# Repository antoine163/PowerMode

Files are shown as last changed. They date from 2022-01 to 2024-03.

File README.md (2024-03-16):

# PowerMod
Module d’alimentation compatible avec les breadboard  
**Note**: Des valeurs de composants restent à finaliser...

## mod_boost_ap3012
Entrée (J1, J2): 5V  
Sortie boost (J3, J4): 24V

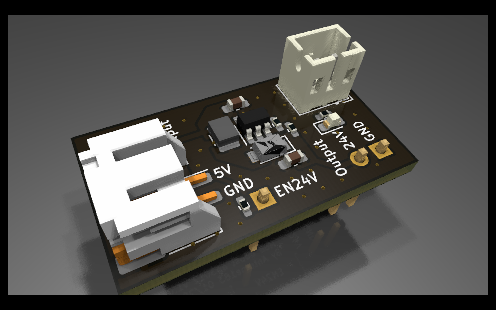
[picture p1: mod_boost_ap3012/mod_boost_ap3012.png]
mod_boost_ap3012


## mod_buck_bd95835efj
Entrée (J1, J2, J6): 12V / 1.5A  
Sortie buck (J4): 5.6V / 2A  
Sortie ldo (J7, J5): 5V / 1.2A  

**Attention:** Le courant max sur l'ensemble des sortie est de 3A.

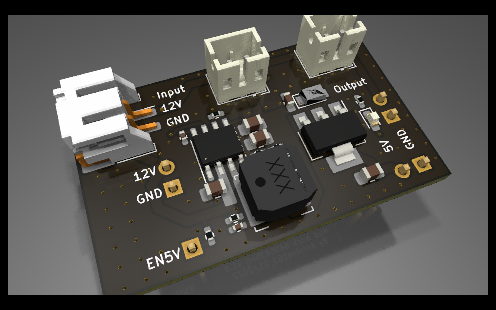
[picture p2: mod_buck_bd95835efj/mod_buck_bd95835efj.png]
mod_buck_bd95835efj


## mod_buck_xc9263
Entrée (J1, J2, J7): 12V  
Sortie 1 buck (J4): 5.35V  
Sortie 1 ldo (J5, J6): 5V / 200mA  
Sortie 2 buck (J8): 3.5V  
Sortie 2 ldo (J5, J6): 3.3V / 250mA  
Sortie 3 buck (J9): 2.1V  
Sortie 3 ldo (J5, J6): 1.8V / 200mA  

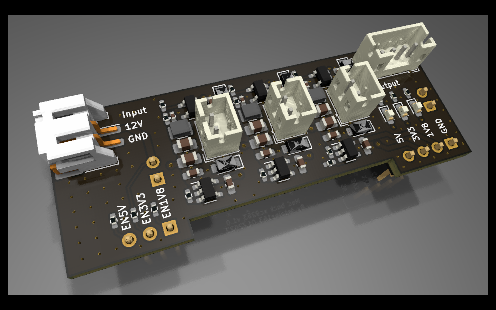
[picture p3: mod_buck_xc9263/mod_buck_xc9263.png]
mod_buck_xc9263
 
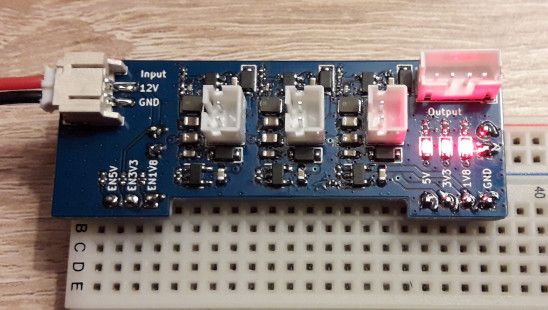
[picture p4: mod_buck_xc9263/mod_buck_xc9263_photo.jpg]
mod_buck_xc9263


# Models 3D
Certains modèles 3D ne sont pas inclus dans ce projet. Il vous faudra les télécharger sur le site des fabricants si vous en avez besoin.

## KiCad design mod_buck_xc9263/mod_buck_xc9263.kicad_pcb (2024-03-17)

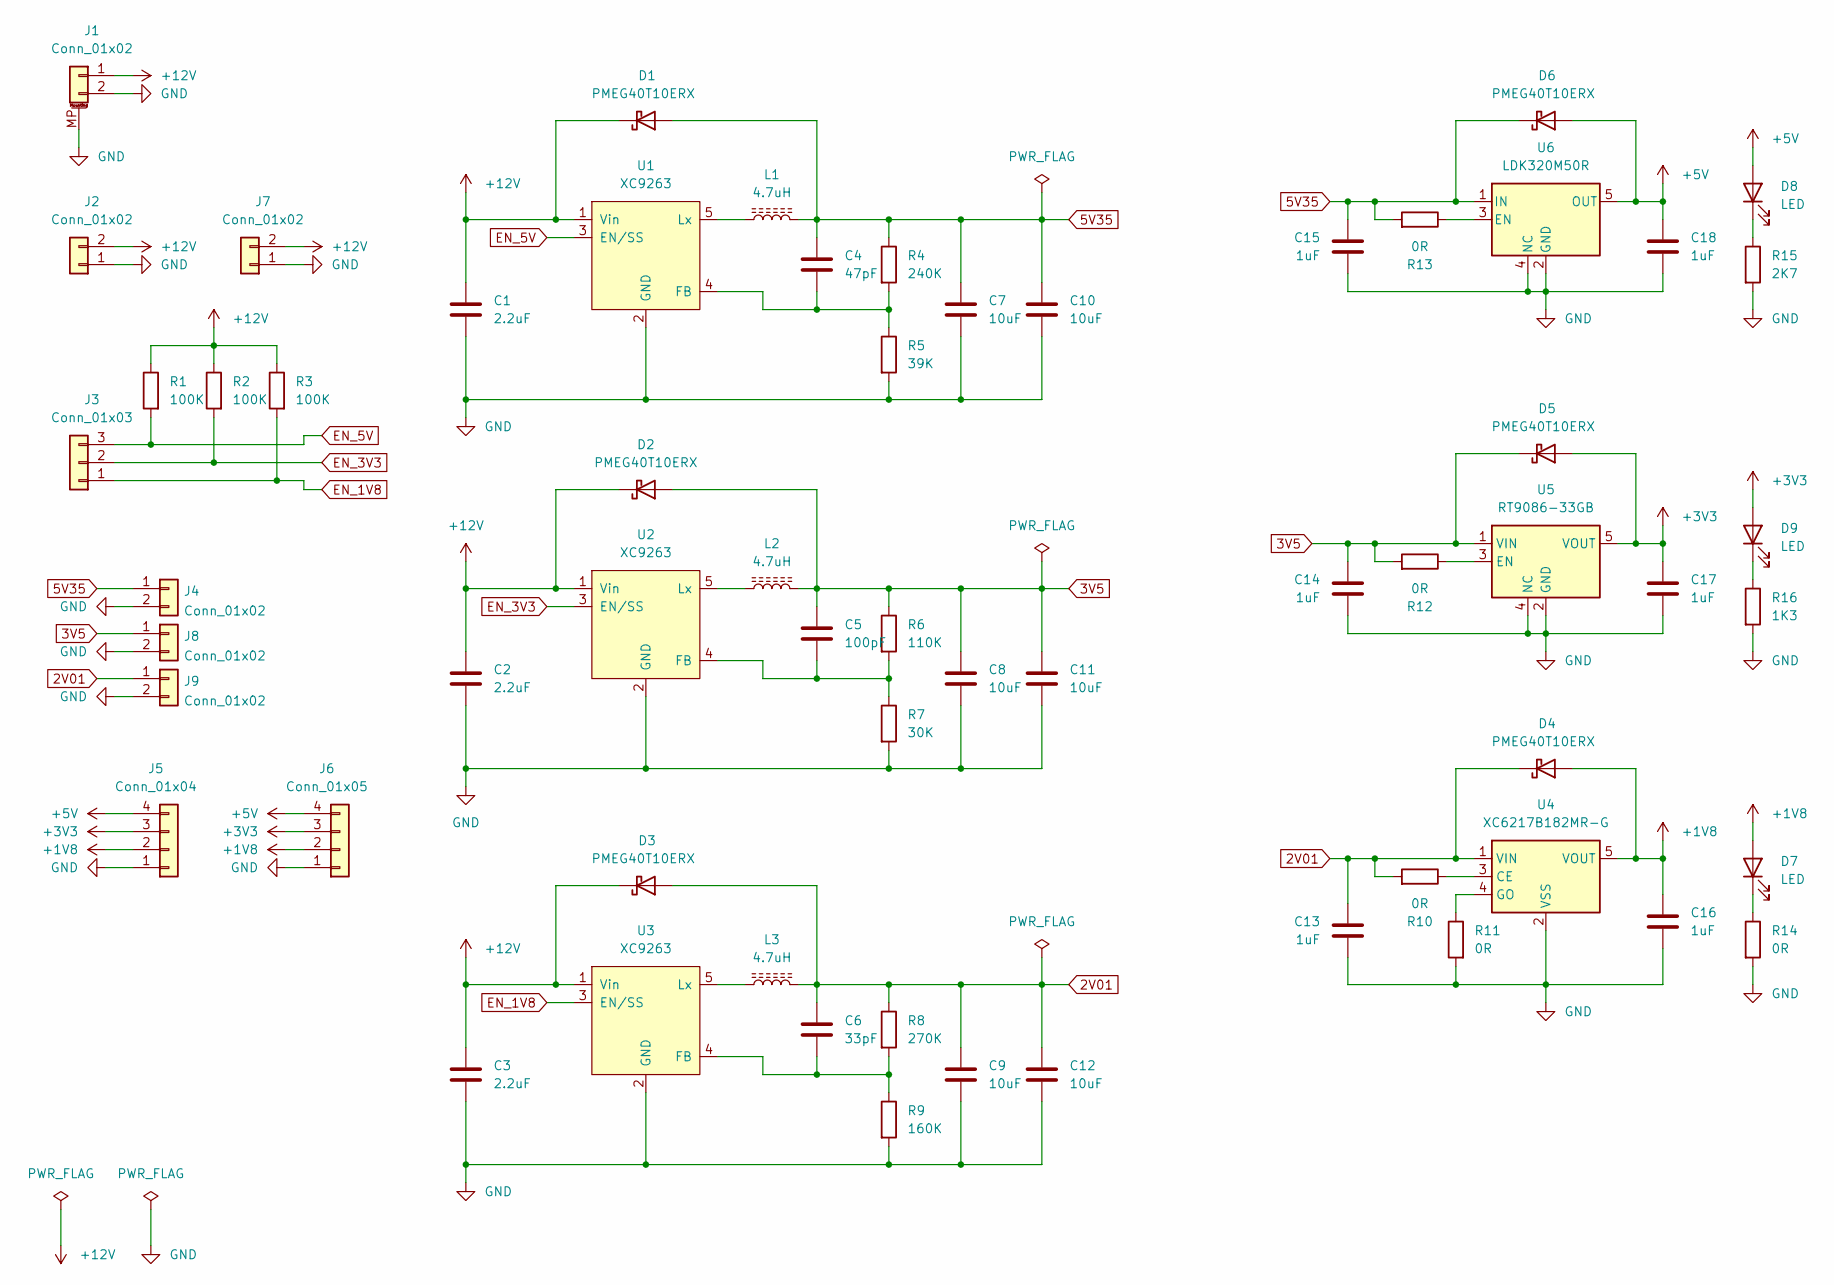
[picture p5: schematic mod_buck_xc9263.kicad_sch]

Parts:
C1, C2, C3: 2.2uF; C_0603_1608Metric_Pad1.08x0.95mm_HandSolder
C4: 47pF; C_0402_1005Metric_Pad0.74x0.62mm_HandSolder
C5: 100pF; C_0402_1005Metric_Pad0.74x0.62mm_HandSolder
C6: 33pF; C_0402_1005Metric_Pad0.74x0.62mm_HandSolder
C7, C8, C9, C10, C11, C12: 10uF; C_0805_2012Metric_Pad1.18x1.45mm_HandSolder
C13, C14, C15, C16, C17, C18: 1uF; C_0603_1608Metric_Pad1.08x0.95mm_HandSolder
D1, D2, D3, D4, D5, D6: PMEG40T10ERX; Nexperia_CFP3_SOD-123W
D7, D8, D9: LED; LED_0603_1608Metric_Pad1.05x0.95mm_HandSolder
J1: Conn_01x02; JST_PH_S2B-PH-SM4-TB_1x02-1MP_P2.00mm_Horizontal
J2, J7: Conn_01x02; PinHeader_1x02_P2.54mm_Vertical
J3: Conn_01x03; PinHeader_1x03_P2.54mm_Vertical
J4, J8, J9: Conn_01x02; JST_PH_B2B-PH-K_1x02_P2.00mm_Vertical
J5: Conn_01x04; JST_PH_B4B-PH-K_1x04_P2.00mm_Vertical
J6: Conn_01x05; PinHeader_1x04_P2.54mm_Vertical
L1, L2, L3: 4.7uH; L_TDK_VLS252012HBX_Handsoldering
R1, R2, R3: 100K; R_0402_1005Metric_Pad0.72x0.64mm_HandSolder
R4: 240K; R_0402_1005Metric_Pad0.72x0.64mm_HandSolder
R5: 39K; R_0402_1005Metric_Pad0.72x0.64mm_HandSolder
R6: 110K; R_0402_1005Metric_Pad0.72x0.64mm_HandSolder
R7: 30K; R_0402_1005Metric_Pad0.72x0.64mm_HandSolder
R8: 270K; R_0402_1005Metric_Pad0.72x0.64mm_HandSolder
R9: 160K; R_0402_1005Metric_Pad0.72x0.64mm_HandSolder
R10, R11, R12, R13, R14: 0R; R_0402_1005Metric_Pad0.72x0.64mm_HandSolder
R15: 2K7; R_0402_1005Metric_Pad0.72x0.64mm_HandSolder
R16: 1K3; R_0402_1005Metric_Pad0.72x0.64mm_HandSolder
U1, U2, U3: XC9263; SOT-23-5
U4: XC6217B182MR-G; SOT-23-5
U5: RT9086-33GB; SOT-23-5
U6: LDK320M50R; SOT-23-5

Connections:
2V01: C6.1, C9.1, C12.1, C13.2, D3.2 (A), D4.1 (K), J9.1, L3.2, R8.1, R10.2, U4.1 (VIN)
3V5: C5.1, C8.1, C11.1, C14.2, D2.2 (A), D5.1 (K), J8.1, L2.2, R6.1, R12.2, U5.1 (VIN)
5V35: C4.1, C7.1, C10.1, C15.2, D1.2 (A), D6.1 (K), J4.1, L1.2, R4.1, R13.2, U6.1 (IN)
+1V8: C16.1, D4.2 (A), D7.2 (A), J5.2, J6.2, U4.5 (VOUT)
+3V3: C17.1, D5.2 (A), D9.2 (A), J5.3, J6.3, U5.5 (VOUT)
+5V: C18.1, D6.2 (A), D8.2 (A), J5.4, J6.4, U6.5 (OUT)
+12V: C1.1, C2.1, C3.1, D1.1 (K), D2.1 (K), D3.1 (K), J1.1, J2.2, J7.2, R1.1, R2.1, R3.1, U1.1 (Vin), U2.1 (Vin), U3.1 (Vin)
EN_1V8: J3.1, R3.2, U3.3 (EN/SS)
EN_3V3: J3.2, R2.2, U2.3 (EN/SS)
EN_5V: J3.3, R1.2, U1.3 (EN/SS)
GND: C1.2, C2.2, C3.2, C7.2, C8.2, C9.2, C10.2, C11.2, C12.2, C13.1, C14.1, C15.1, C16.2, C17.2, C18.2, J1.2, J1.MP (MountPin), J2.1, J4.2, J5.1, J6.1, J7.1, J8.2, J9.2, R5.2, R7.2, R9.2, R11.2, R14.2, R15.2, R16.2, U1.2 (GND), U2.2 (GND), U3.2 (GND), U4.2 (VSS), U5.2 (GND), U5.4 (NC), U6.2 (GND), U6.4 (NC)
unnamed: C4.2, R4.2, R5.1, U1.4 (FB)
unnamed: C5.2, R6.2, R7.1, U2.4 (FB)
unnamed: C6.2, R8.2, R9.1, U3.4 (FB)
unnamed: D7.1 (K), R14.1
unnamed: D8.1 (K), R15.1
unnamed: D9.1 (K), R16.1
unnamed: L1.1, U1.5 (Lx)
unnamed: L2.1, U2.5 (Lx)
unnamed: L3.1, U3.5 (Lx)
unnamed: R10.1, U4.3 (CE)
unnamed: R11.1, U4.4 (GO)
unnamed: R12.1, U5.3 (EN)
unnamed: R13.1, U6.3 (EN)

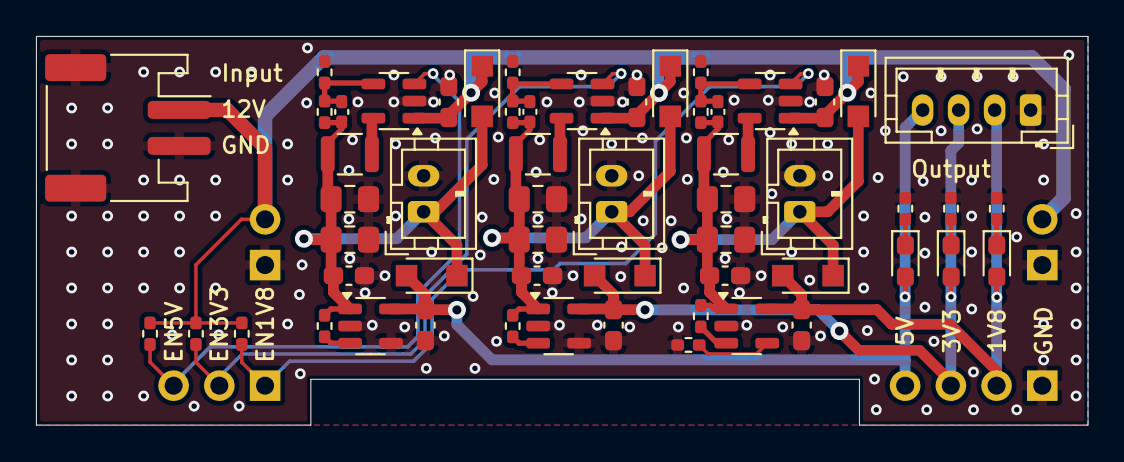
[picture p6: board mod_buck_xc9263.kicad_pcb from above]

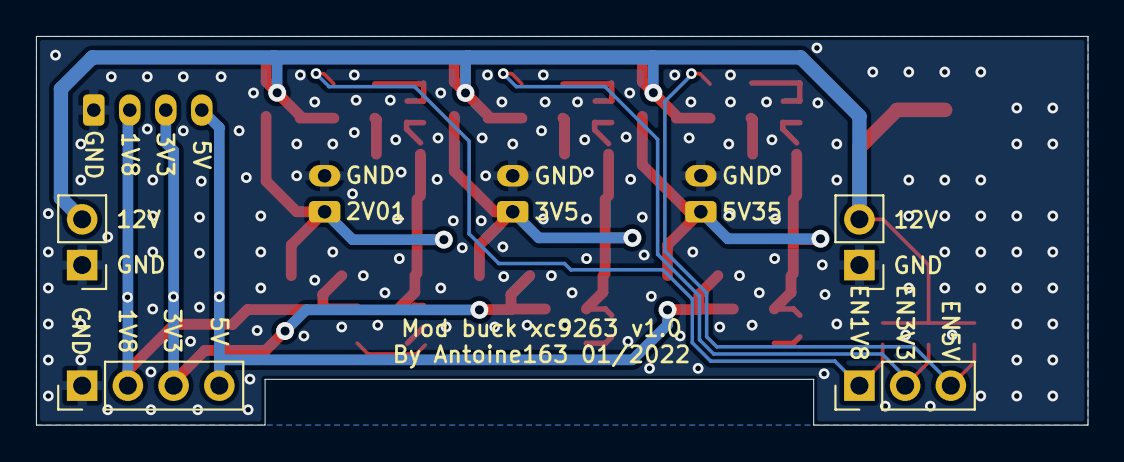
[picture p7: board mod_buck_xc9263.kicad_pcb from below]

Board: 2 copper layers, 58.4 x 21.6 mm, 61 parts (4 on the bottom side), 24 nets.

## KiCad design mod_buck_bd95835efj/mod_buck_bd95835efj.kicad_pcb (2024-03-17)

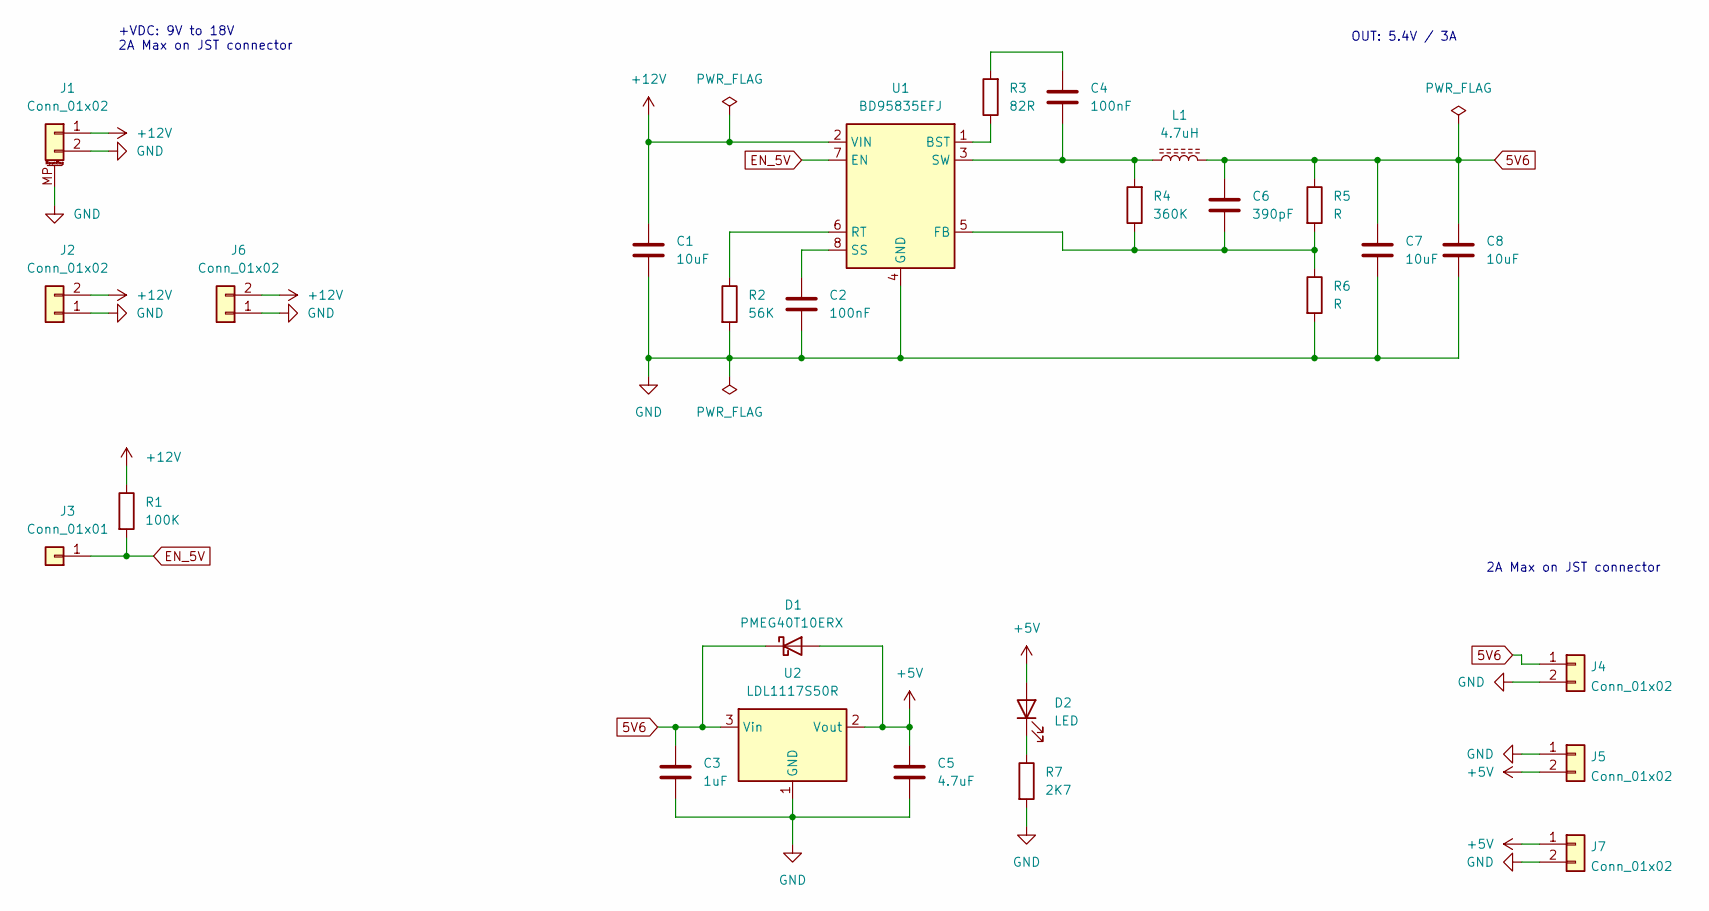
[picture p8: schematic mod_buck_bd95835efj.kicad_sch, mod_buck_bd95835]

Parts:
C1, C7, C8: 10uF; C_0805_2012Metric_Pad1.18x1.45mm_HandSolder
C2, C4: 100nF; C_0402_1005Metric_Pad0.74x0.62mm_HandSolder
C3: 1uF; C_0603_1608Metric_Pad1.08x0.95mm_HandSolder
C5: 4.7uF; C_0805_2012Metric_Pad1.18x1.45mm_HandSolder
C6: 390pF; C_0402_1005Metric_Pad0.74x0.62mm_HandSolder
D1: PMEG40T10ERX; Nexperia_CFP3_SOD-123W
D2: LED; LED_0603_1608Metric_Pad1.05x0.95mm_HandSolder
J1: Conn_01x02; JST_PH_S2B-PH-SM4-TB_1x02-1MP_P2.00mm_Horizontal
J2, J5, J6: Conn_01x02; PinHeader_1x02_P2.54mm_Vertical
J3: Conn_01x01; PinHeader_1x01_P2.54mm_Vertical
J4, J7: Conn_01x02; JST_PH_B2B-PH-K_1x02_P2.00mm_Vertical
L1: 4.7uH; L_TDK_VLS6045AF_Handsoldering
R1: 100K; R_0402_1005Metric_Pad0.72x0.64mm_HandSolder
R2: 56K; R_0402_1005Metric_Pad0.72x0.64mm_HandSolder
R3: 82R; R_0402_1005Metric_Pad0.72x0.64mm_HandSolder
R4: 360K; R_0402_1005Metric_Pad0.72x0.64mm_HandSolder
R5, R6: R; R_0402_1005Metric_Pad0.72x0.64mm_HandSolder
R7: 2K7; R_0402_1005Metric_Pad0.72x0.64mm_HandSolder
U1: BD95835EFJ; HTSOP-8-1EP_3.9x4.9mm_P1.27mm_EP2.4x3.2mm_ThermalVias
U2: LDL1117S50R; SOT-223-3_TabPin2

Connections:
5V6: C3.1, C6.1, C7.1, C8.1, D1.1 (K), J4.1, L1.2, R5.1, U2.3 (Vin)
+5V: C5.1, D1.2 (A), D2.2 (A), J5.2, J7.1, U2.2 (Vout)
+12V: C1.1, J1.1, J2.2, J6.2, R1.1, U1.2 (VIN)
EN_5V: J3.1, R1.2, U1.7 (EN)
GND: C1.2, C2.2, C3.2, C5.2, C7.2, C8.2, J1.2, J1.MP (MountPin), J2.1, J4.2, J5.1, J6.1, J7.2, R2.2, R6.2, R7.2, U1.4 (GND), U1.9 (GND), U2.1 (GND)
unnamed: C2.1, U1.8 (SS)
unnamed: C4.1, R3.2
unnamed: C4.2, L1.1, R4.2, U1.3 (SW)
unnamed: C6.2, R4.1, R5.2, R6.1, U1.5 (FB)
unnamed: D2.1 (K), R7.1
unnamed: R2.1, U1.6 (RT)
unnamed: R3.1, U1.1 (BST)

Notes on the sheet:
OUT: 5.4V / 3A
2A Max on JST connector
+VDC: 9V to 18V 2A Max on JST connector

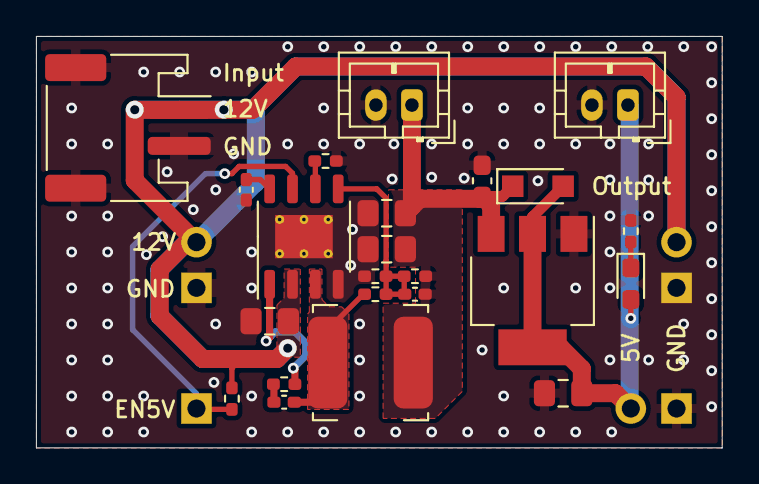
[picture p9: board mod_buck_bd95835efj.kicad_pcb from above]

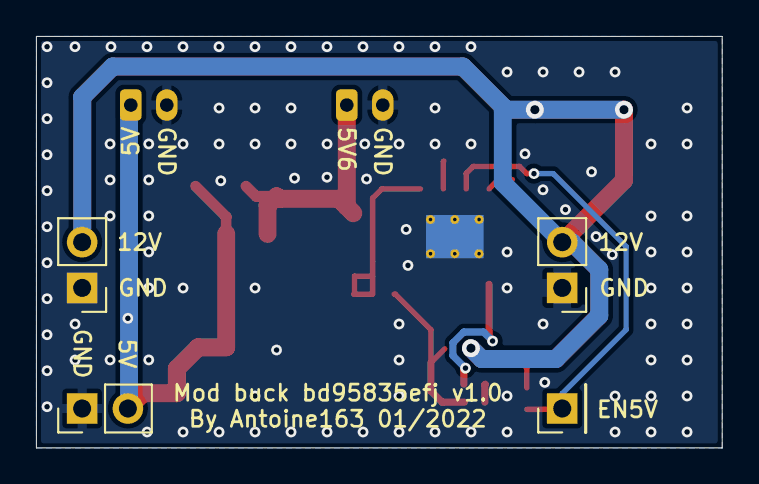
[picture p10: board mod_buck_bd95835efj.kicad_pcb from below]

Board: 2 copper layers, 38.1 x 22.9 mm, 27 parts (4 on the bottom side), 12 nets.

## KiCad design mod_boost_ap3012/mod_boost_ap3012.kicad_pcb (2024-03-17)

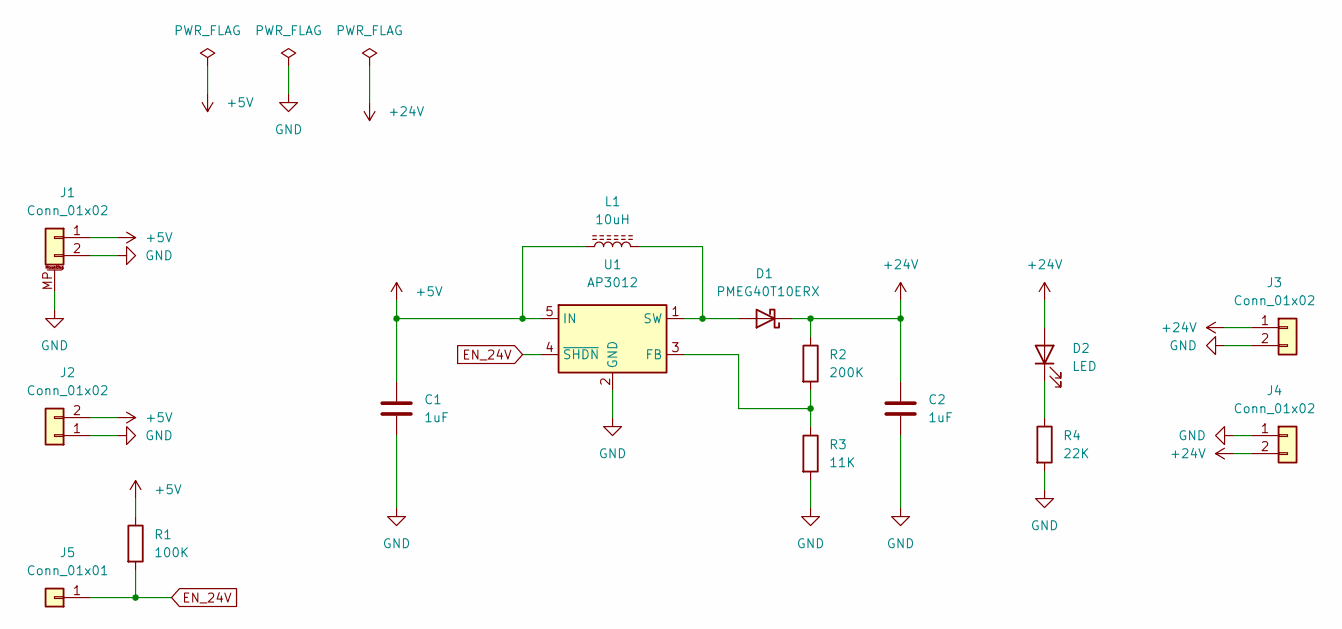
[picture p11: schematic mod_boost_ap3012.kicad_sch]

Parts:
C1, C2: 1uF; C_0603_1608Metric_Pad1.08x0.95mm_HandSolder
D1: PMEG40T10ERX; Nexperia_CFP3_SOD-123W
D2: LED; LED_0603_1608Metric_Pad1.05x0.95mm_HandSolder
J1: Conn_01x02; JST_PH_S2B-PH-SM4-TB_1x02-1MP_P2.00mm_Horizontal
J2, J4: Conn_01x02; PinHeader_1x02_P2.54mm_Vertical
J3: Conn_01x02; JST_PH_B2B-PH-K_1x02_P2.00mm_Vertical
J5: Conn_01x01; PinHeader_1x01_P2.54mm_Vertical
L1: 10uH; L_TDK_VLS252012HBX_Handsoldering
R1: 100K; R_0402_1005Metric_Pad0.72x0.64mm_HandSolder
R2: 200K; R_0402_1005Metric_Pad0.72x0.64mm_HandSolder
R3: 11K; R_0402_1005Metric_Pad0.72x0.64mm_HandSolder
R4: 22K; R_0402_1005Metric_Pad0.72x0.64mm_HandSolder
U1: AP3012; SOT-23-5

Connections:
+5V: C1.1, J1.1, J2.2, L1.1, R1.1, U1.5 (IN)
+24V: C2.1, D1.1 (K), D2.2 (A), J3.1, J4.2, R2.1
EN_24V: J5.1, R1.2, U1.4 (~SHDN)
GND: C1.2, C2.2, J1.2, J1.MP (MountPin), J2.1, J3.2, J4.1, R3.2, R4.2, U1.2 (GND)
unnamed: D1.2 (A), L1.2, U1.1 (SW)
unnamed: D2.1 (K), R4.1
unnamed: R2.2, R3.1, U1.3 (FB)

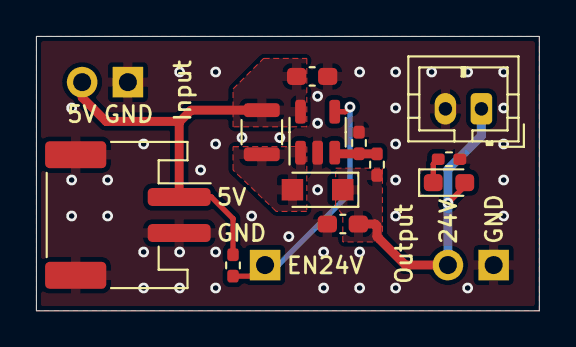
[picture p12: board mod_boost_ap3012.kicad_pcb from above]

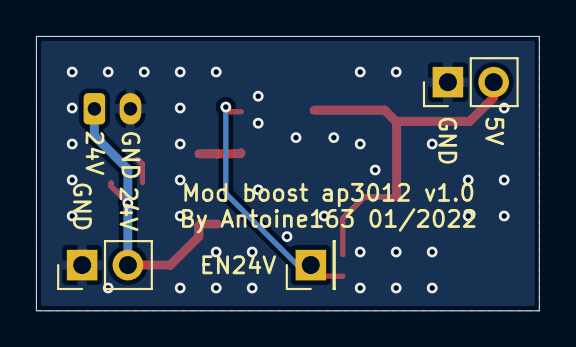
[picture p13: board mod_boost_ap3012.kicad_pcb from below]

Board: 2 copper layers, 27.9 x 15.2 mm, 15 parts (3 on the bottom side), 7 nets.

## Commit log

2022-01-08 Ajout des fichiers kicad
    [mod_boost_ap3012.kicad_pcb, mod_boost_ap3012.kicad_sch, mod_buck_bd95835efj.kicad_pcb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]
2022-01-08 Mise à jour du readme et ajour des visuels
2022-01-08 Ajout des fichiers png
2022-01-27 Ajout photo de la carte Mod_buck_xc9263
2024-03-16 Suppression des models 3D
    [mod_boost_ap3012.kicad_pcb, mod_buck_bd95835efj.kicad_pcb, mod_buck_xc9263.kicad_pcb]
2024-03-16 suppression de maxima-circuits
2024-03-16 ajout maxima-circuits en submodule
2024-03-17 update 3d inductor
    [mod_boost_ap3012.kicad_pcb, mod_buck_bd95835efj.kicad_pcb, mod_buck_xc9263.kicad_pcb]
